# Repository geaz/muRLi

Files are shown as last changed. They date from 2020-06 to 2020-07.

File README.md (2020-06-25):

  


# muRLi
**muRLi** is a WiFi connected and programmable (mu)sic (R)eactive (Li)ght system. It supports custom *MOD* cartridges which contain executable scripts. These scripts are able to influence the light patterns produced by **muRLi**.

Furthermore **muRLi** creates a naive mesh including a *websocket*. **muRLiN**s (muRLi nodes) are able to connect to this mesh and will create an additional access point and websocket for other nodes to connect to. This way nodes not in range of **muRLi** are also able to join the mesh as long as at least one **muRLiN** is in range. The nodes are able to receive *commands* created by **muRLi**. The *commands* contain color information to which the **muRLiN**s will react.

*Everything combined, it is possible to span a mesh of WiFi connected devices which are synchronously reacting to music.*

> *Click the image for a video of it in action!*
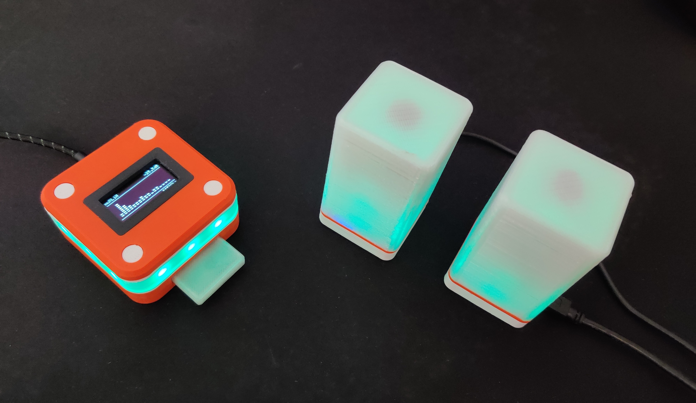
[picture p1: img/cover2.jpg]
muRLi (https://www.youtube.com/watch?v=Lw6lD8utsBI)


# Table of Contents
1. [3D Model](#3d-model)
2. [muRLi](#murli)  
    a) [BOM](#bom)  
    b) [Firmware](#firmware)  
    c) [Build](#build)
3. [MODs](#mods)  
    a) [BOM (for one MOD)](#BOM-for-one-MOD)  
    b) [Build MOD](#mod-build)  
    c) [Create MODs](#create-mods)  
    d) [Write MODs](#write-mods)
4. [muRLiN](#murlin)  
    a) [BOM](#node-bom)  
    b) [Firmware](#node-firmware)  
    c) [Build](#node-build)

## 3D Model
The models were designed in Fusion 360. The exported STLs are included in the Github repository (*stl* folder). Furthermore there are Fusion 360 archive files ready to download (*cad* folder).

## muRLi

### BOM

- 3D Printed Parts
- 1x Wemos D1 Mini
- 1x 1K Resistor
- 1x Capacitor 680uF
- 1x MAX4466
- 1x 1x5 DuPont Male Pin Header
- [9x WS2812B LEDs (I used a strip and cut it)](https://www.amazon.de/dp/B01CDTED80)
- 4x M2x12mm screws
- 4x M3x4mm screws
- [Stripboard](https://www.amazon.com/dp/B00C9NXP94)
- Wire
- Hotglue & Superglue

### Firmware

Before building **muRLi** you should flash the firmware onto the Wemos D1 Mini. This way you are able to make sure that it is functional. Open the project in [Visual Studio Code](https://code.visualstudio.com/). The project uses [PlatformIO](https://platformio.org/platformio-ide) to develop the firmware. Install the PlatformIO extension into Visual Studio Code, if not already done. 

To flash the firmware onto the Wemos connect it to your PC, make sure that the **-DBUILD_MURLI** build flag is active in the *platformio.ini* file and press the *Upload* button in the status bar.

muRLi - Flash

Afterwards start the *serial monitor* and you should see some outputs like in the screenshot below. If you are able to see the output, the device is working and you are ready to build **muRLi**.

muRLi - Serial

### Build

First of all, make yourself comfortable with the following schematics. It shows you all parts of **muRLi** which are necessary to connect to each other. We will use a piece of stripboard for each wire which is not directly connected to the Wemos D1 Mini. Mostly to provide power to each part.

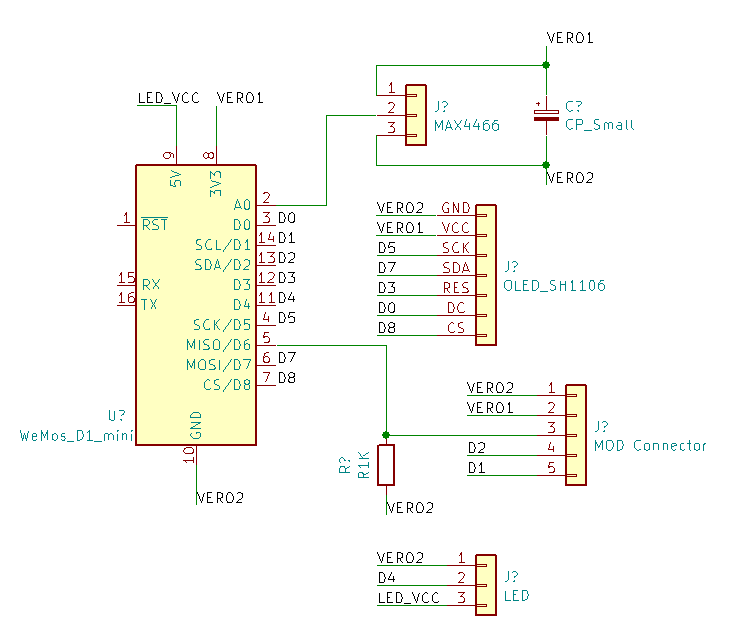
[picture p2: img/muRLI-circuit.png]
muRLi - Schematics


Now that you made yourself comfortable with the wiring, take the *Top* part and the *Frame* and glue them together with the superglue. I recommend to place something heavy on top to make sure that they bond well.

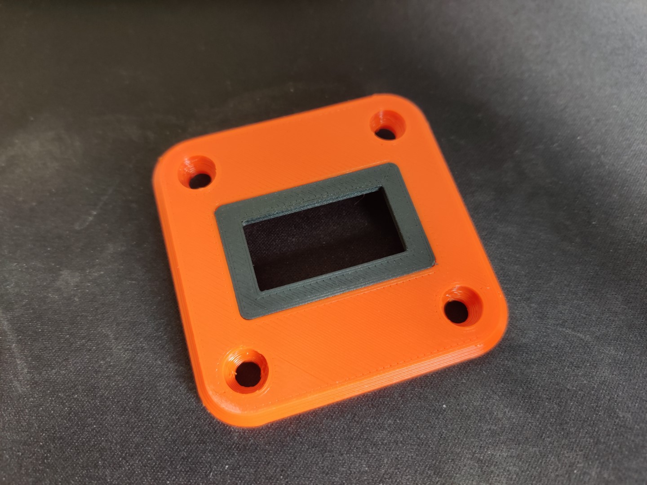
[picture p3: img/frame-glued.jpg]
muRLi - Frame Glued


Solder wires to your display and mount it to the *Top* part.

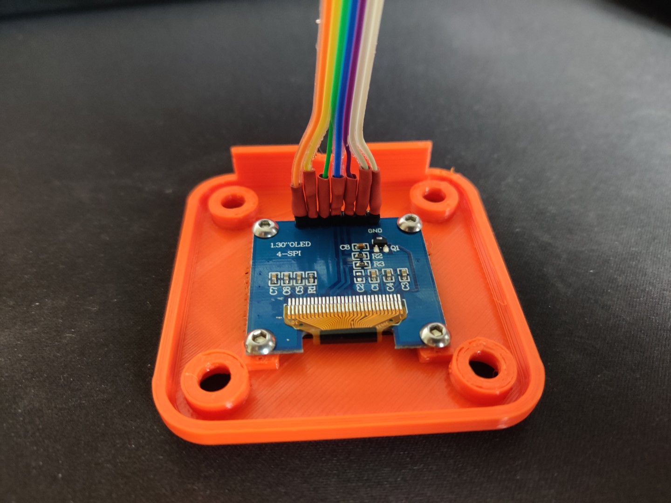
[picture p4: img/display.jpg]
muRLi - Display


To diffuse the LEDs a bit, the *middle* part has a small slot for a paper insert. Take a bit of paper and cut it into a narrow stripe and insert it into the slot.

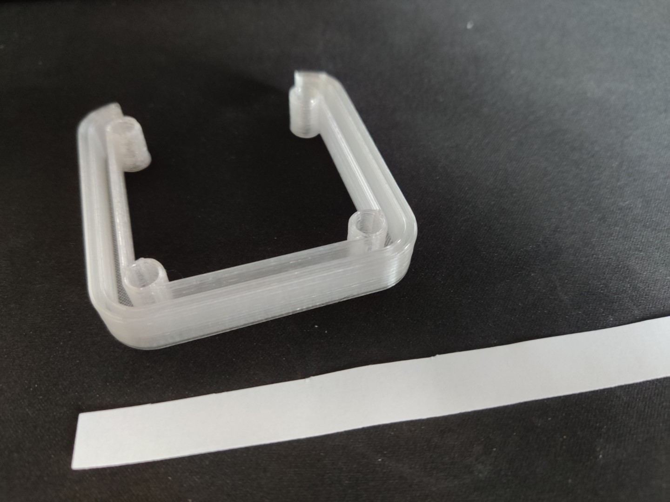
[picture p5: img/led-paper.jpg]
muRLi - LED Paper


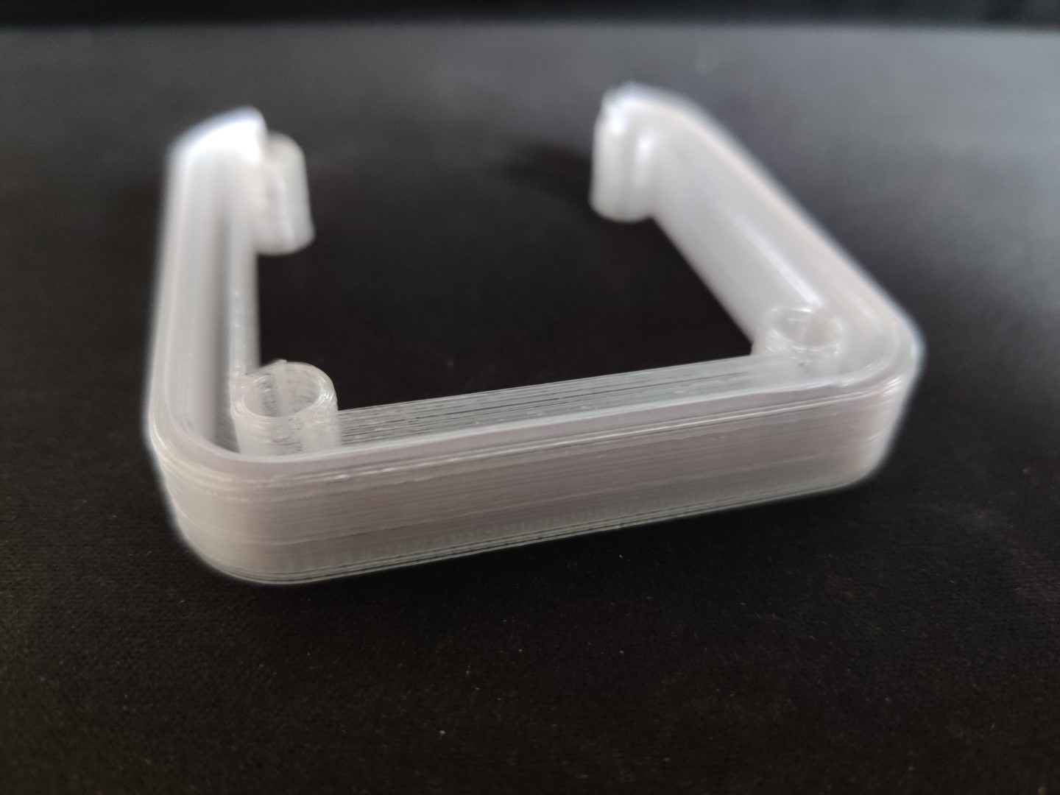
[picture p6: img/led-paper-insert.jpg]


Solder three wires to your nine LED stripe and insert it into the *middle* part, too - **pay attention to the data line direction**. I bent the cables away from the back of the shell to avoid any possible interference between the microphone cables and the LEDs.

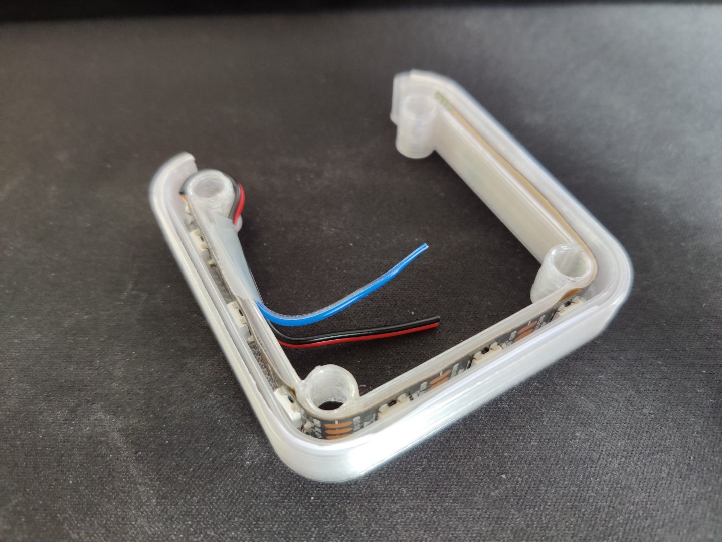
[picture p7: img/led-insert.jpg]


Solder three wires to your microphone and attach it with hotglue to the *Bottom* part of the shell.

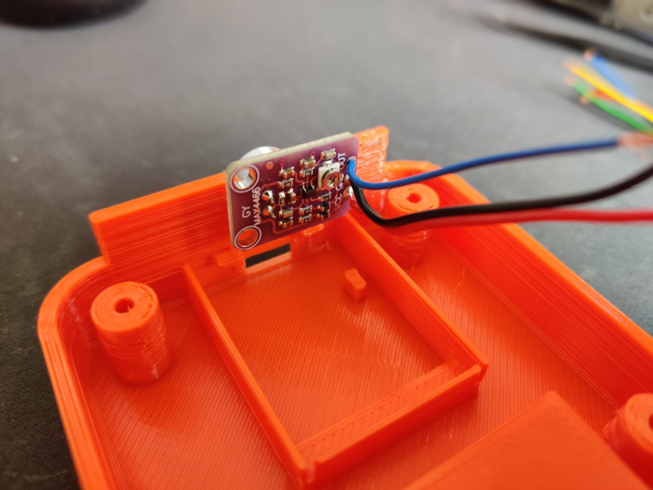
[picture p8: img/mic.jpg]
muRLi - Mic


At this point I advise you to build your first [MOD](#mods). A *MOD* will help to align the MOD connector correctly in the *bottom* shell.   

**Playing jingle ...**

Now that your fist **MOD** is done, take the stripboard and create one 4x7 and one 2x5 sized piece. Picture below as a reference - pay attention to the copper line directions.

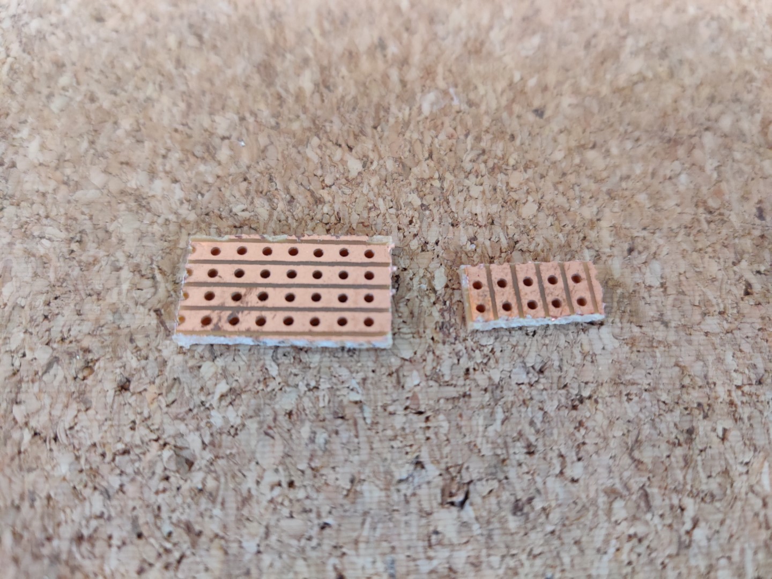
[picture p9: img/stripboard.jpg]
muRLi - Stripboard


Solder the DuPont male pin header to one row of the 2x5 stripboard piece and five wires to the second row. The wires should be directed to the opposite side of the pin header and should sit flush. Otherwise the connector will not sit correctly in the cartridge slot. 

Now insert the *MOD* connector into the slot of the *Bottom* part of the shell and try to insert your *MOD*. If they fit, hotglue the connector to the shell. This way the connector and the *MOD*s will align perfectly.

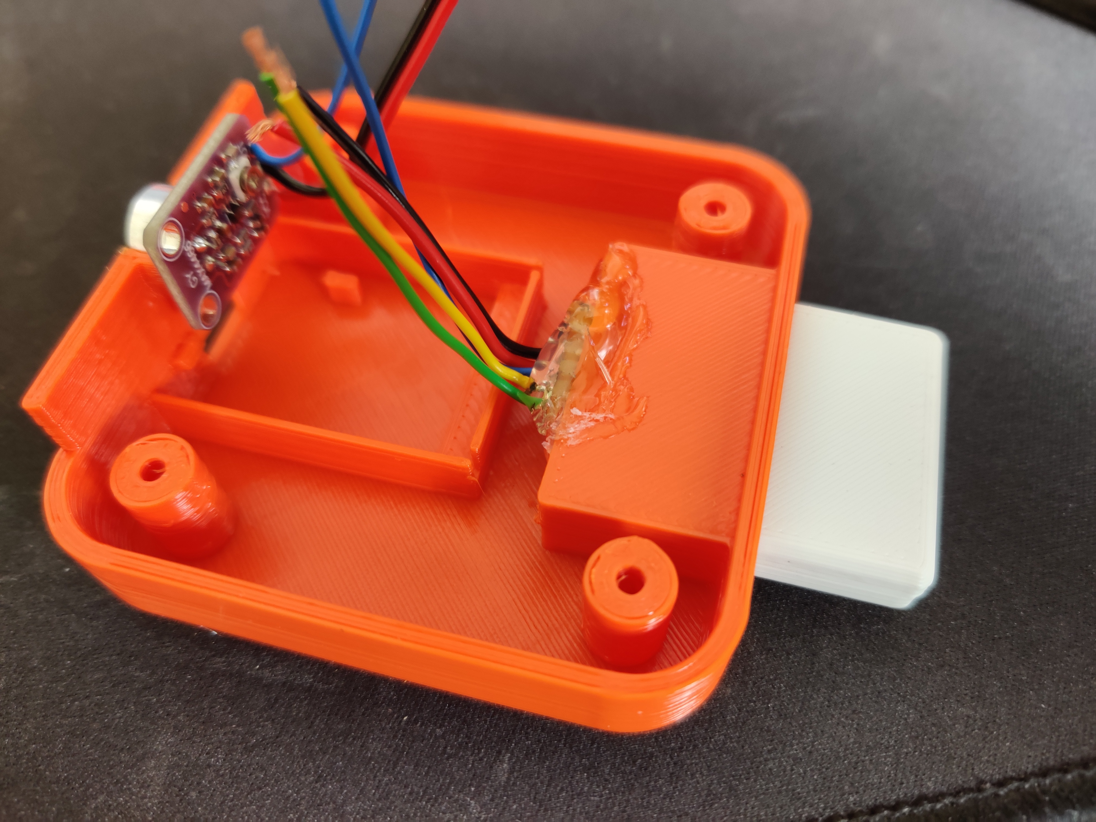
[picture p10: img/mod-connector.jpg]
muRLi - MOD Connector


Take the 4x7 stripboard you prepared before and solder all necessary components and wires as shown in the image below. The ground wires are only indicated (read the red comment) to keep the image tidy. Also solder every other wire like indicated in the above schematics.

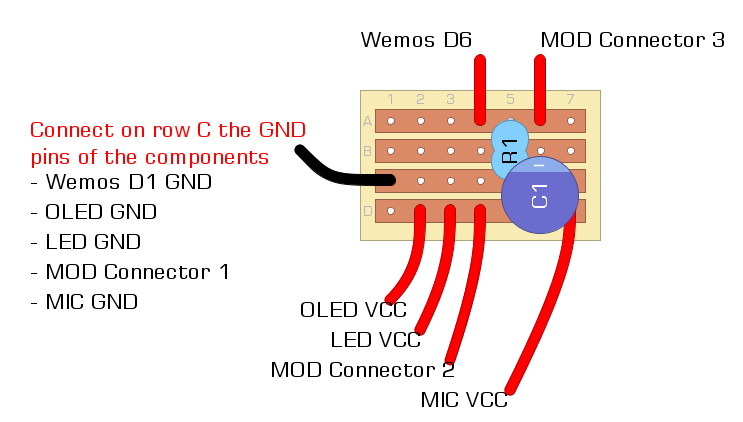
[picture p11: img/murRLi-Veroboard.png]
muRLi - Veroboard


Mount the Wemos D1 Mini to the *Bottom* part of the shell.

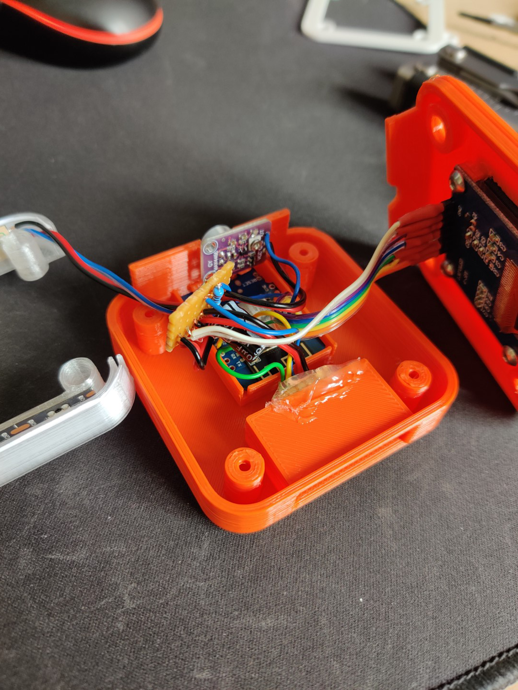
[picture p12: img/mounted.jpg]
muRLi - Mounted


Power the Wemos and insert a *MOD*. You should see the *decibel* in the top right of the display. Set the gain of you microphone with a small screwdriver. It should float between -40 and -43dB in a silent room. If done, place the stripboard into the shell, place one of the *divider* parts on top of the *bottom* part, then place the *middle* part on top of it. Followed by an additional *divider* and the *top* part.
Insert the *bolts* into the four holes and use the M2x12mm screws to close the shell.

## MODs

### BOM (for one MOD)

- 3D Printed Parts
- 1x 24LC32A
- 1x 1x5 DuPont Female Connector
- Superglue
- Wire

###  Build

Building a MOD cartridge is quite easy. Just take a bit of wire, the *23LC32A* and the DuPont connector and solder it as shown in the schematics.

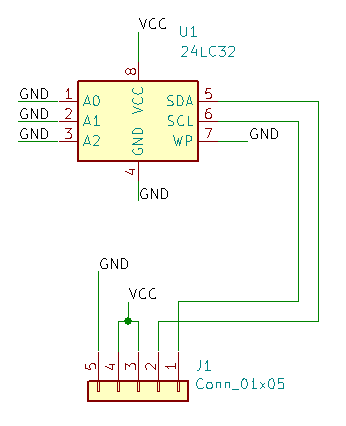
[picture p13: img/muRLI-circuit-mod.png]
muRLi MOD - Schematics


Here is a picture of my first one. Not pretty, but it works.

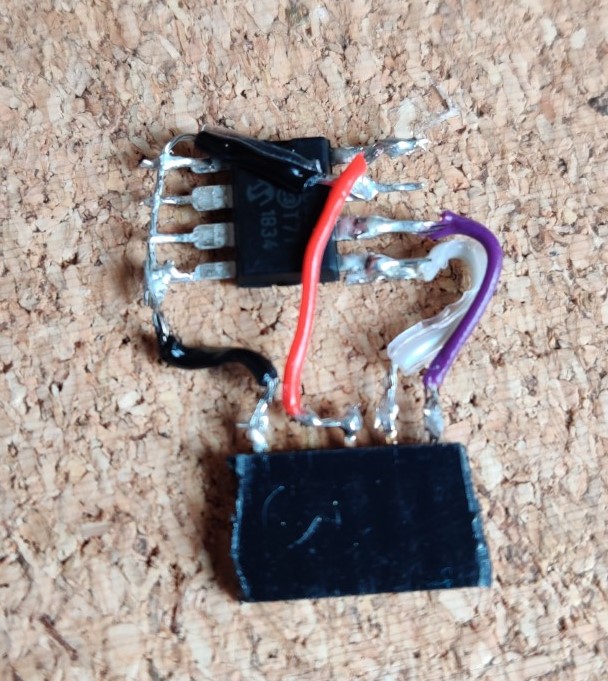
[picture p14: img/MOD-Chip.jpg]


Take a bit of superglue and attach the DuPont connector to the cartridge shell. Make sure that the *ground pin* is oriented to the side of the shell **without the gap** and that it sits in the middle of the gap! Otherwise you will have a hard time to insert it into the MOD slot.

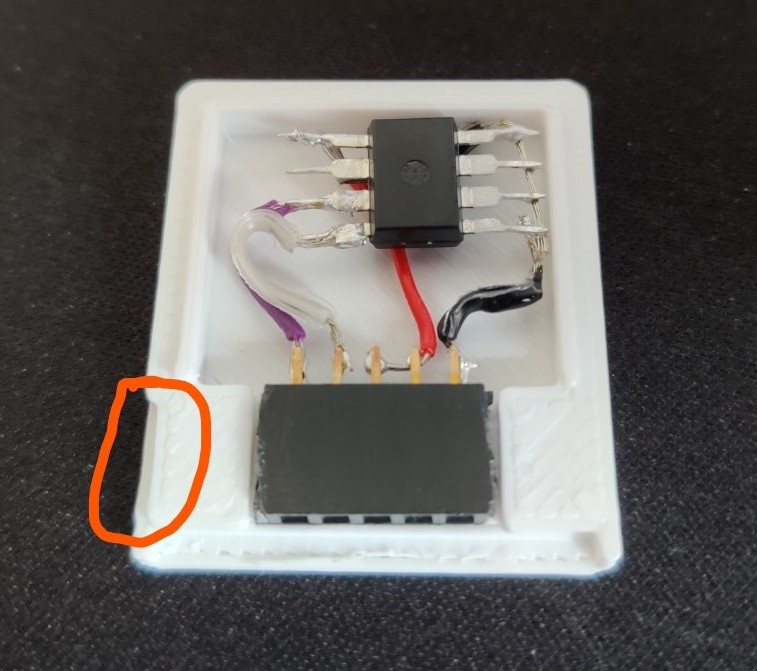
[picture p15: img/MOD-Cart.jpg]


Now just glue the two shell halves together and you are done.

### Create MODs

**murli** uses [mJS](https://github.com/cesanta/mjs/) to execute the MODs.
On every loop the scripts will get some variables injected by **muRLi**.

- **vol** *The calculated volume is a value between 0 and 100*
- **freq** *The dominant frequency of the current loop*
- **lVol** *The volume of the last loop*
- **lFreq** *The dominant frequency of the last loop*
- **minF** *The lowest frequency registered by muRLi - 130hz -> Lowest note for viola, mandola*
- **midF** *The middle frequency value - 1046hz -> Highest note reproducible by average female*
- **maxF** *The highest frequency registered by muRLi - 3140 -> Between highest note on a flute and on a 88-key piano* 
- **mLedC** *The total number of LEDs in the longest mesh route*
- **pLedC** *Number of LEDs prior of the current executing node*
- **nLedC** *Number of LEDs of the current executing node*
- **pNodeC** *Number of previous nodes in route*

Every script has to implement the *init*, *update* and *getName* method:

```
function init() {}
function update(delta) {}
function getName(){ return "NAME"; }
```

The script API exposes some methods to work with:

- **map(x, in_min, in_max, out_min, out_max)** *Maps a number in a certain range to the corresponding number in the output range*
- **round(number)** *Rounds a number to the next whole integer*
- **xrgb(r, g, b)** *Returns the hex representation of the given RGB color*
- **xhsv(h, s, v)** *Returns the hex representation of the given HSV color*
- **setDelay(count)** *If set to a value >0 the script engine will delay the frequency updates. For example with a value of '1', the script engine would delay the frequency updates by one other frequency update.*
- **setLed(index, hexColor)** *Set the LED with the given index to the given hex color*
- **getLed(index)** *Get the hex color of the given LED*
- **setGroup(index, [led1, led2, ...])** *Set a group of an array of leds to the given index - For example setGroup(0, [0,1]): a setLed(0) would now set index 0 and 1 together*
- **clearGroups()** *Clear all previous group definitions*

Look into the *mod* folder for some examples. If you write your own mod, try to avoid objects and arrays as much as possible. They are perfomance killers!

### Write MODs

In the *mods* folder is a python script to write the mods onto the cartridges. Please make sure, that Python 3 is installed.
Connect **muRLi** to your machine, insert a cartridge and execute the script like this:

```
python writeMod.py COM4 simple.murli
```

The python script will tell you, if something went wrong. **muRLi** will show a *MOD saved*, if everything went well.
If you run the script without any parameters, it will list all available COM ports.

## muRLiN

**muRLiN**s are devices which are able to connect to the *websocket* provided by **muRLi** or a closer available other **muRLiN** via WiFi. Because every **muRLiN** is also an access point and a websocket server it is possible to span a pretty big mesh of **muRLiN**s.

This repository provides a simple example for a **muRLiN**. But it is possible to create other devices like for example wall mounted LED devices which will connect to **muRLi** to create some nice color effects. Or desk lamp like devices. Just play with your imagination and come up with some cool devices. All you have to do is to take a *Wemos D1 Mini* connect some LEDs and flash the **muRLiN** firmware on it.

###  BOM

- 3D Printed Parts
- Wemos D1 Mini
- 1x 330 Ohm Resistor
- [4x4 WS2812B LEDs (I used a strip and cut it)](https://www.amazon.de/dp/B01CDTED80)
- 4x M2x12mm screws
- Wire

###  Firmware

The upload works like the firmware upload for *muRLi*. Just set the **-DLED_COUNT** build flag to *16* and swap the **-DBUILD_MURLI** flag for the **-DBUILD_MURLINODE** flag.

###  Build

Insert the four led strips into the *middle* part. And solder them together - **keep the direction of the data line in mind!**

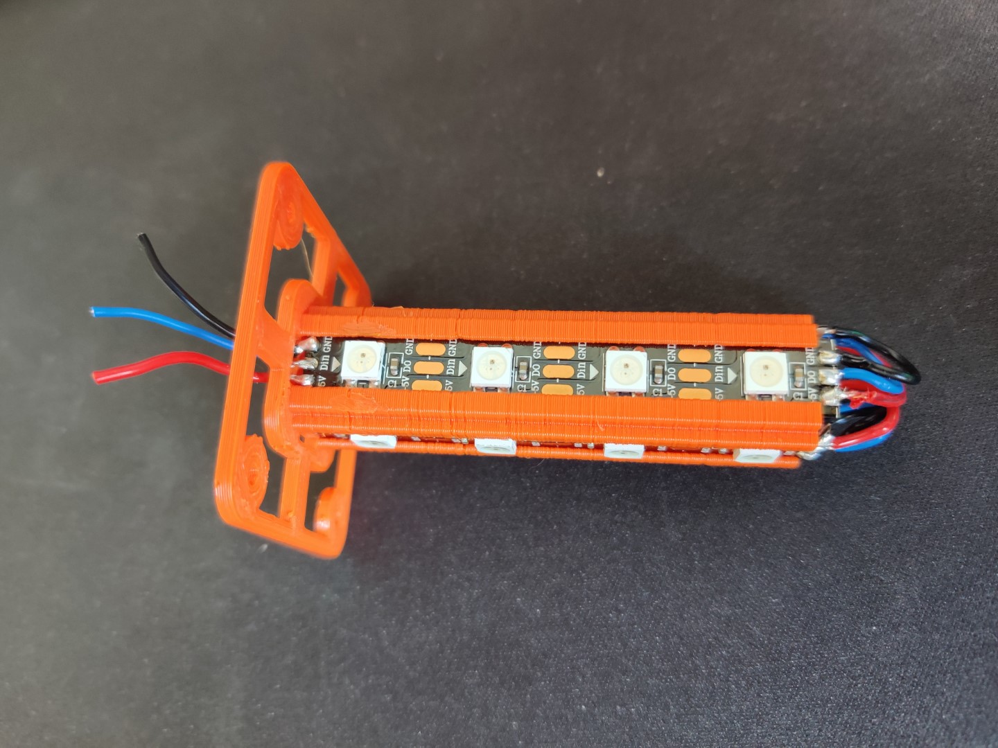
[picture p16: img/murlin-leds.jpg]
muRLiN-leds


Solder the LEDs to the *Wemos D1 Mini*. *VCC* to *5V*, *GND* to *GND* and *DataIn* to *D4*. Next, solder the 300Ohm resistor to the pins *RST* and *D0* and insert the *D1 Mini* into the *bottom* part.

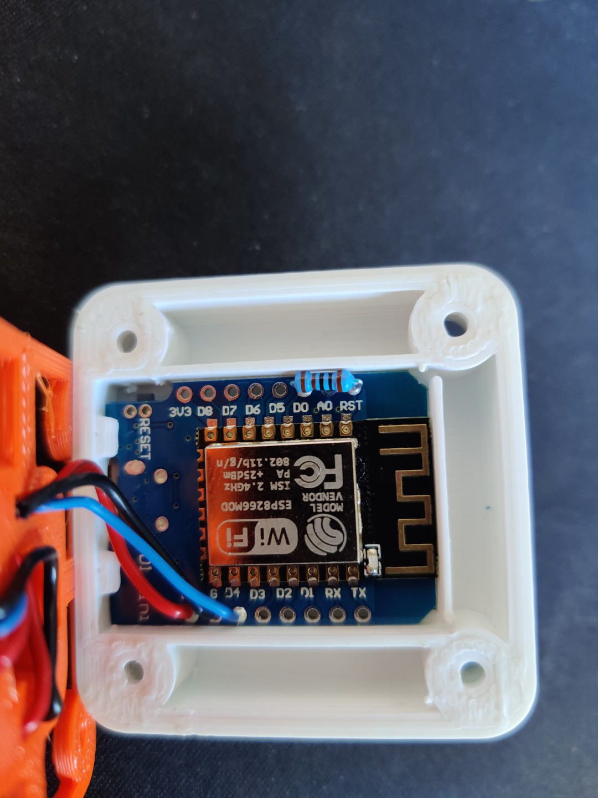
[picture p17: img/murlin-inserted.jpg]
muRLiN-inserted


Cut four pieces of paper and insert them into the slots of the *top* part.

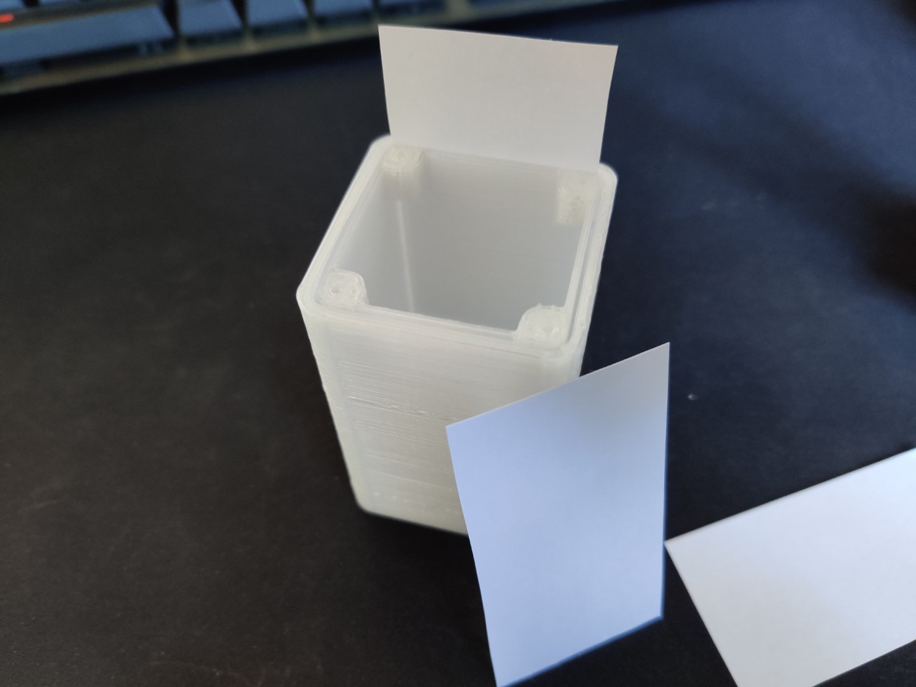
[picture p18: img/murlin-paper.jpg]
muRLiN-paper


Now place everything together and close it with the screws. You are done!

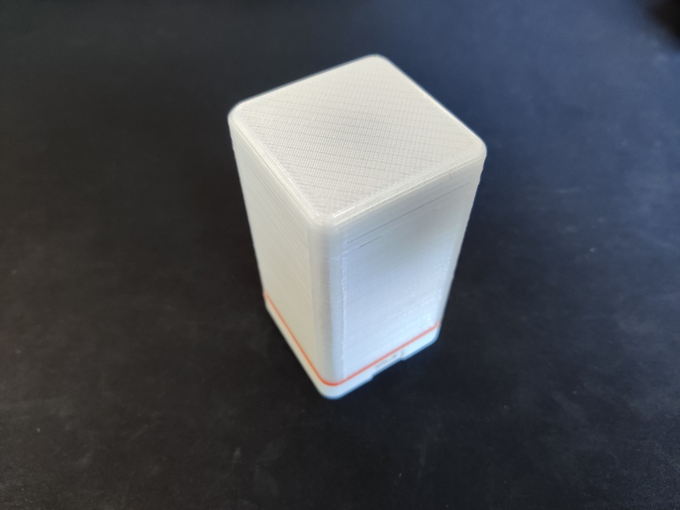
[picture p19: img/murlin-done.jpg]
muRLiN-done


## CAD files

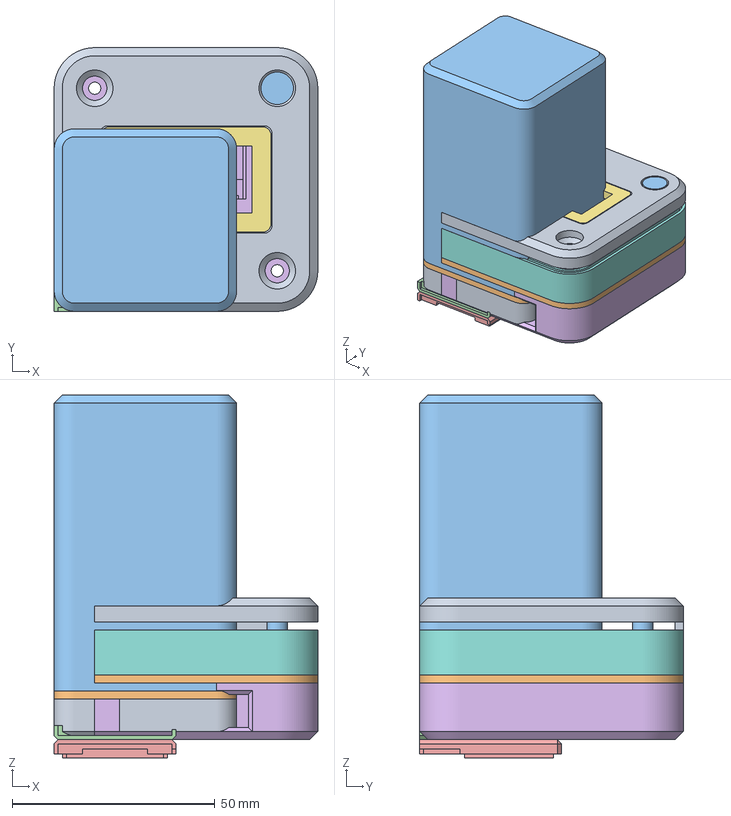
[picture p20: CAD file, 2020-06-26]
muRLi.3mf
65.0 x 65.0 x 89.5 mm
Bottom.stl
Middle.stl
Top.stl
Mod Bottom.stl
Mod Top.stl
1x Bottom.stl
1x Frame.stl
1x Middle.stl
1x Top.stl
2x Divider.stl
4x Bolt.stl

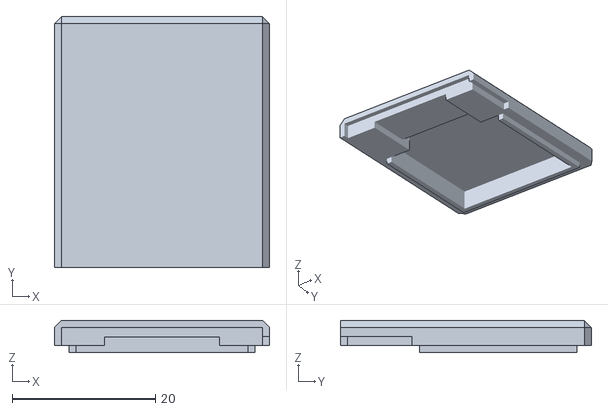
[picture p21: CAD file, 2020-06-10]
stl/MOD/Mod Top.stl
30.0 x 35.0 x 4.50

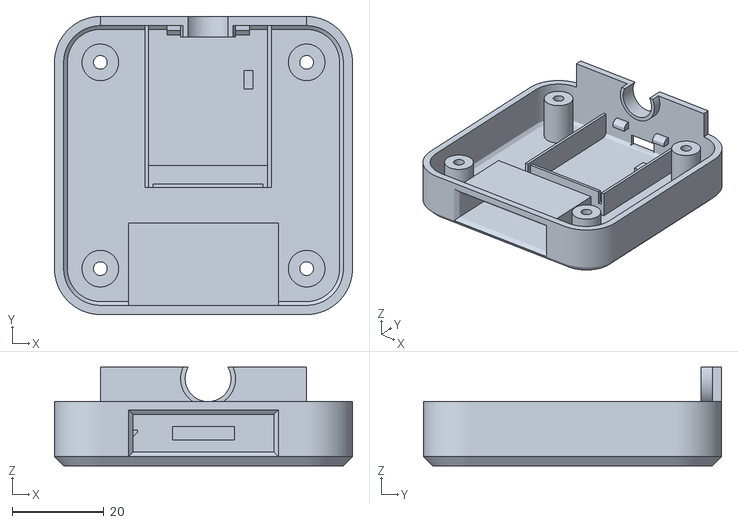
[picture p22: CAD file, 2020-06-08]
stl/muRLi/1x Bottom.stl
65.0 x 65.0 x 21.5

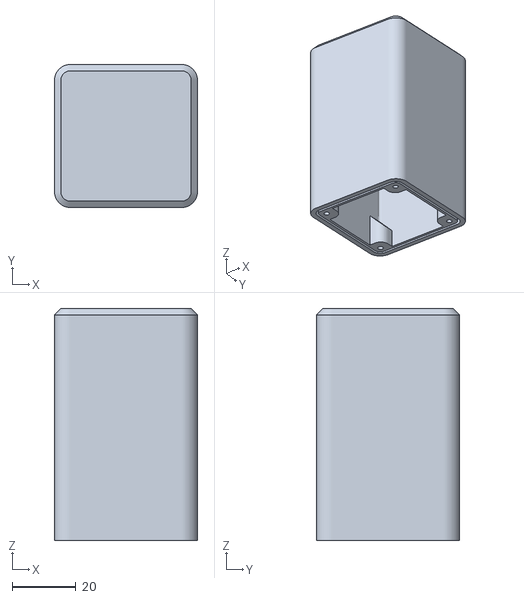
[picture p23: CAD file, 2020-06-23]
stl/muRLiN/Top.stl
45.0 x 45.0 x 73.0

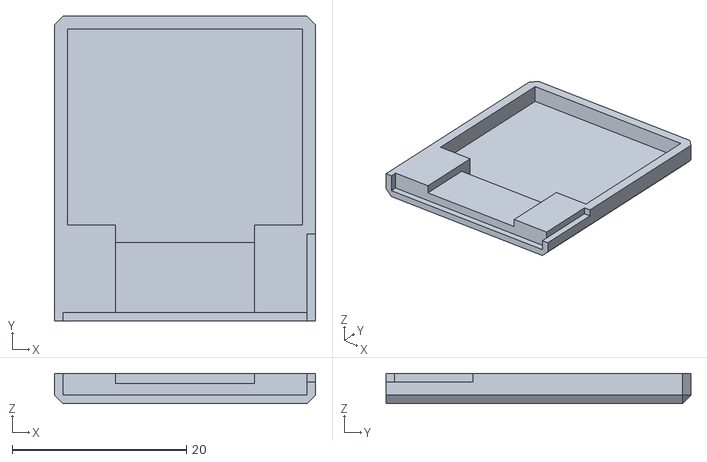
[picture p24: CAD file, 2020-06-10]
stl/MOD/Mod Bottom.stl
30.0 x 35.0 x 3.50

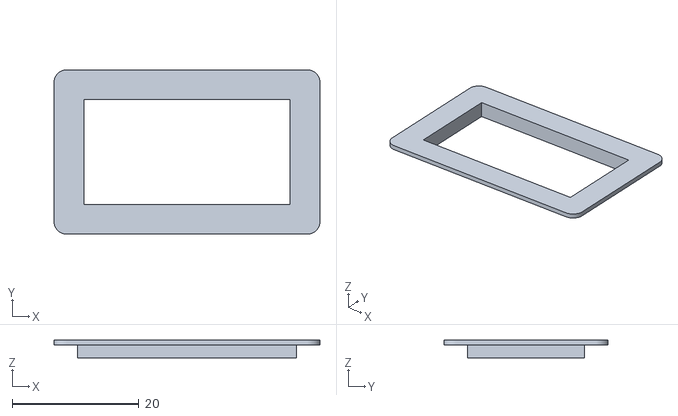
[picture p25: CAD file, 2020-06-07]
stl/muRLi/1x Frame.stl
41.9 x 25.9 x 2.80

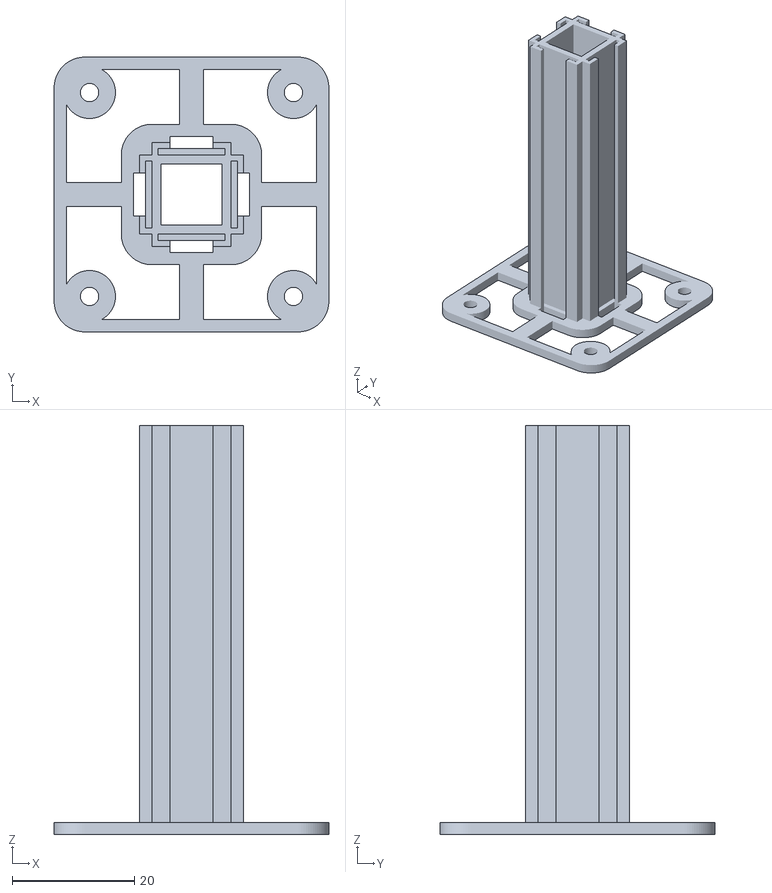
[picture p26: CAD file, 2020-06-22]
stl/muRLiN/Middle.stl
45.0 x 45.0 x 67.0

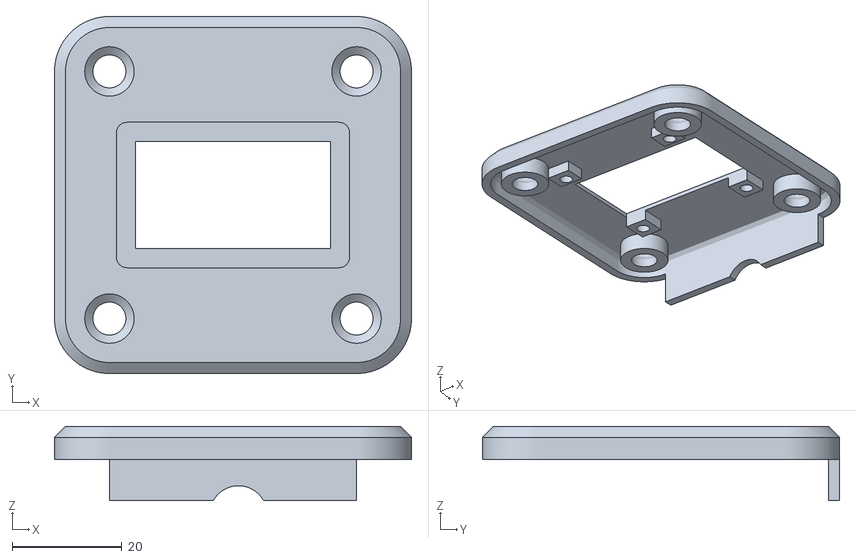
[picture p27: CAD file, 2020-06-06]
stl/muRLi/1x Top.stl
65.0 x 65.0 x 13.5

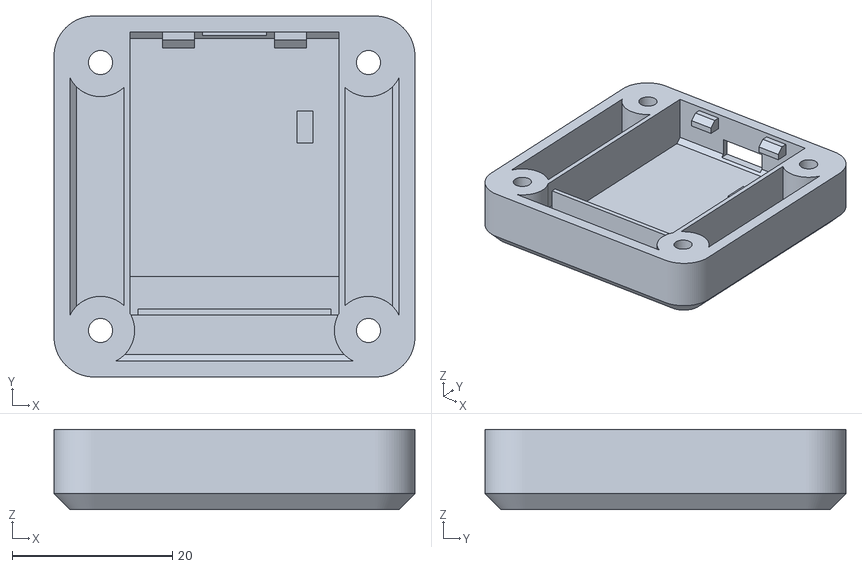
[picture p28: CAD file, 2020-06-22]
stl/muRLiN/Bottom.stl
45.0 x 45.0 x 10.0

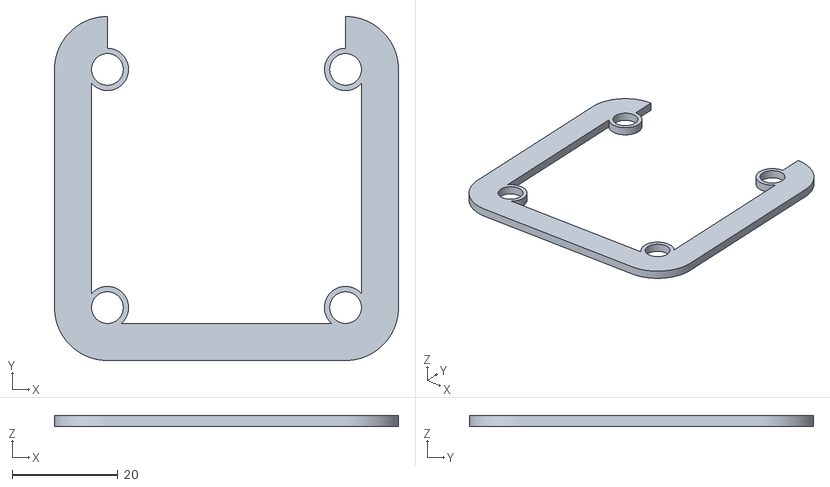
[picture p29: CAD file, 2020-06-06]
stl/muRLi/2x Divider.stl
65.0 x 65.0 x 2.00

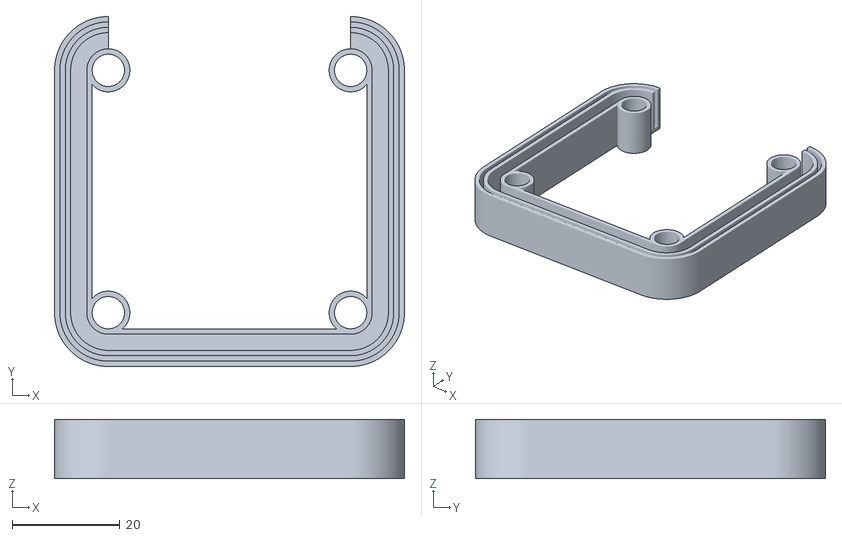
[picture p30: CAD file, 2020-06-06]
stl/muRLi/1x Middle.stl
65.0 x 65.0 x 11.0

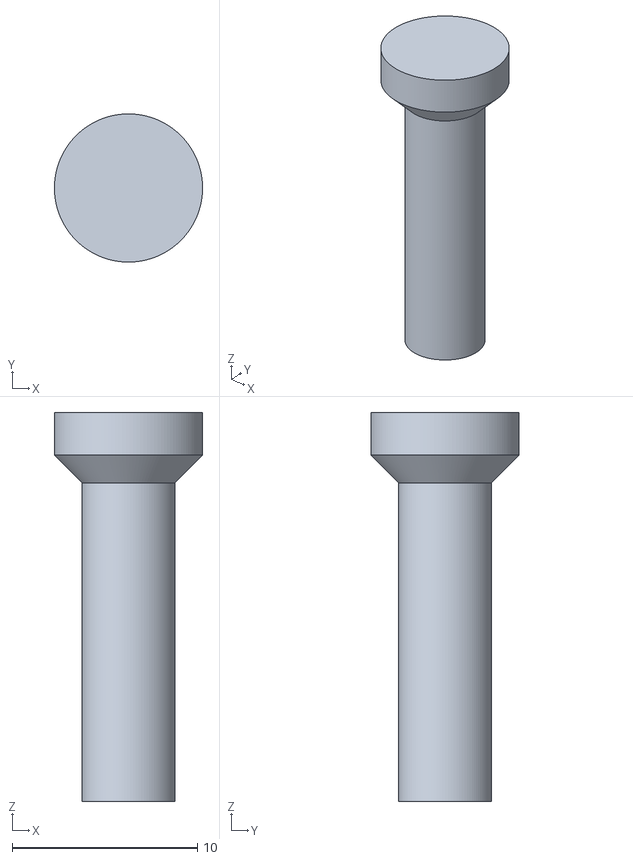
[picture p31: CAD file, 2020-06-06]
stl/muRLi/4x Bolt.stl
8.00 x 8.00 x 21.0

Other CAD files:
cad/Mod.f3d
cad/muRLi.f3z
cad/muRLiN.f3d

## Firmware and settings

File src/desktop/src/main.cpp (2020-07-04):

#include <toml.hpp>
#include <iostream>
#include <client_commands.hpp>
#include <server_commands.hpp>

#include "murli_desktop.hpp"

int main(int argc, char* argv[])
{
    const auto tomlConfig  = toml::parse("config.toml");
    const auto& murliConfig = toml::find(tomlConfig, "murli");
    const auto url  = toml::find<std::string>(murliConfig, "url");

    Murli::Desktop::MurliDesktop desktopApp(url);
    desktopApp.run();
}

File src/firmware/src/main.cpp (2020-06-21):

#ifdef BUILD_MURLI

#include "murli/murli_context.hpp"

Murli::MurliContext murliContext;

void setup()
{
    Serial.begin(74880);
    Serial.println("Starting muRLi...");
    Wire.begin();

    murliContext.setup();
    
    pinMode(A0, INPUT);         // Mic Input
    pinMode(D6, INPUT);         // Check if module inserted
    pinMode(LED_PIN, OUTPUT);   // LED
}

void loop() 
{
    murliContext.loop();
}

#elif BUILD_MURLINODE

#include "murli/murliN_context.hpp"

Murli::MurlinContext murlinContext;

void setup()
{
    Serial.begin(74880);
    Serial.println("Starting muRLiN ...");

    murlinContext.setup();

    pinMode(LED_PIN, OUTPUT);    
}

void loop()
{
    murlinContext.loop();
}

#endif

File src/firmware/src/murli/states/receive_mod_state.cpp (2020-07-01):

#ifndef RECEIVEMODSTATE_H
#define RECEIVEMODSTATE_H

#include "write_result_state.cpp"
#include "write_mod_state.cpp"
#include "../state.hpp"
#include "../murli_context.hpp"
#include "../../views/icon_text_view.cpp"

namespace Murli
{
    class ReceiveModState : public State
    {
        public:
            ReceiveModState(const uint16_t modSize) : _modSize(modSize)
            {
                _writeModView = std::make_shared<IconTextView>("Receiving MOD ...", u8g2_font_open_iconic_embedded_2x_t, 69);
            }

            void run(MurliContext& context)
            {
                context.getDisplay().setView(_writeModView);
                context.getDisplay().loop();

                if(_receivedMod.size() != _modSize && Serial.available())
                {
                    while(Serial.available() > 0)
                    {
                        _receivedMod.push_back(Serial.read());
                    }
                    // ACK chunk
                    if(_receivedMod.size() % 128 == 0 || _receivedMod.size() == _modSize)
                    {
                        Serial.write(30);
                    }
                }
                else if(_receivedMod.size() == _modSize)
                {
                    context.currentState = std::make_shared<WriteModState>(_receivedMod);
                }
                else
                {
                    Serial.write(31);
                    context.writeRequested = false;                    
                    context.currentState = std::make_shared<WriteResultState>(false, "Error receiving mod!");
                } 
            }
        
        private:
            uint16_t _modSize;
            std::vector<uint8_t> _receivedMod;
            std::shared_ptr<IconTextView> _writeModView;
    };
}

#endif // RECEIVEMODSTATE_H

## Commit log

2020-05-31 Remove modName and switch to HWSPI
2020-06-06 Add schematics
    [muRLi.sch]
2020-06-06 Add STLs
    [1x Bottom.stl, 1x Frame.stl, 1x Middle.stl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]
2020-06-06 Add MOD circuit
    [MOD.sch, muRLi.sch]
2020-06-06 STL updates
    [1x Top.stl, 2x Divider.stl]
2020-06-07 Update STLs
    [1x Frame.stl, Mod Bottom.stl, Mod Top.stl]
2020-06-07 Add Fusion360 Archives
    [Mod.f3d, muRLi.f3z]
2020-06-07 Cut images
2020-06-07 Move STLs
    [1x Bottom.stl, 1x Frame.stl, 1x Middle.stl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]
2020-06-08 Small Bottom Part change
    [1x Bottom.stl, muRLi.f3z]
2020-06-08 Change LED count
2020-06-10 Fix schematics
    [muRLi.sch]
2020-06-10 Add LED Count parameter
2020-06-10 Change MOD model
    Removed one mm from the lip at the bottom
    [Mod Bottom.stl, Mod Top.stl, Mod.f3d]
2020-06-14 Add LED Count as define
2020-06-14 Change LED Pin to define
2020-06-14 Remove test prints
2020-06-16 Change view and led logic
2020-06-20 Refactoring of murliN and Fix Mod Callback
    [main.cpp, murliN_context.cpp, murli_context.cpp]
2020-06-22 Add muRLiN STLs
    [Bottom.stl, Middle.stl, Top.stl]
2020-06-22 Fix LED on Read
    [script_context.cpp]
2020-06-22 Update muRLiN STLs
    [Middle.stl, Top.stl]
2020-06-22 Add muRLiN CAD
    [muRLiN.f3d]
2020-06-22 Fix Top part chamfer
    [Top.stl, muRLiN.f3d]
2020-06-23 Some fixes
    [Top.stl, muRLiN.f3d]
2020-06-26 Add 3MF
    [muRLi.3mf]

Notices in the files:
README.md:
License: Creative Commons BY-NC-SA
